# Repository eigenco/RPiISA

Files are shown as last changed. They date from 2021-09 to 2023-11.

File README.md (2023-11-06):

# RPiISA
Raspberry Pi to ISA bus, including Adlib emulation and PCB

Emulator to ISA (e.g. VGA-adapter), i.e. files in the directories beginning 20231105, correspond to this video: 

https://www.youtube.com/watch?v=V3mTAtPauRs

Portions of the emulator code are from this project: https://github.com/adriancable/8086tiny

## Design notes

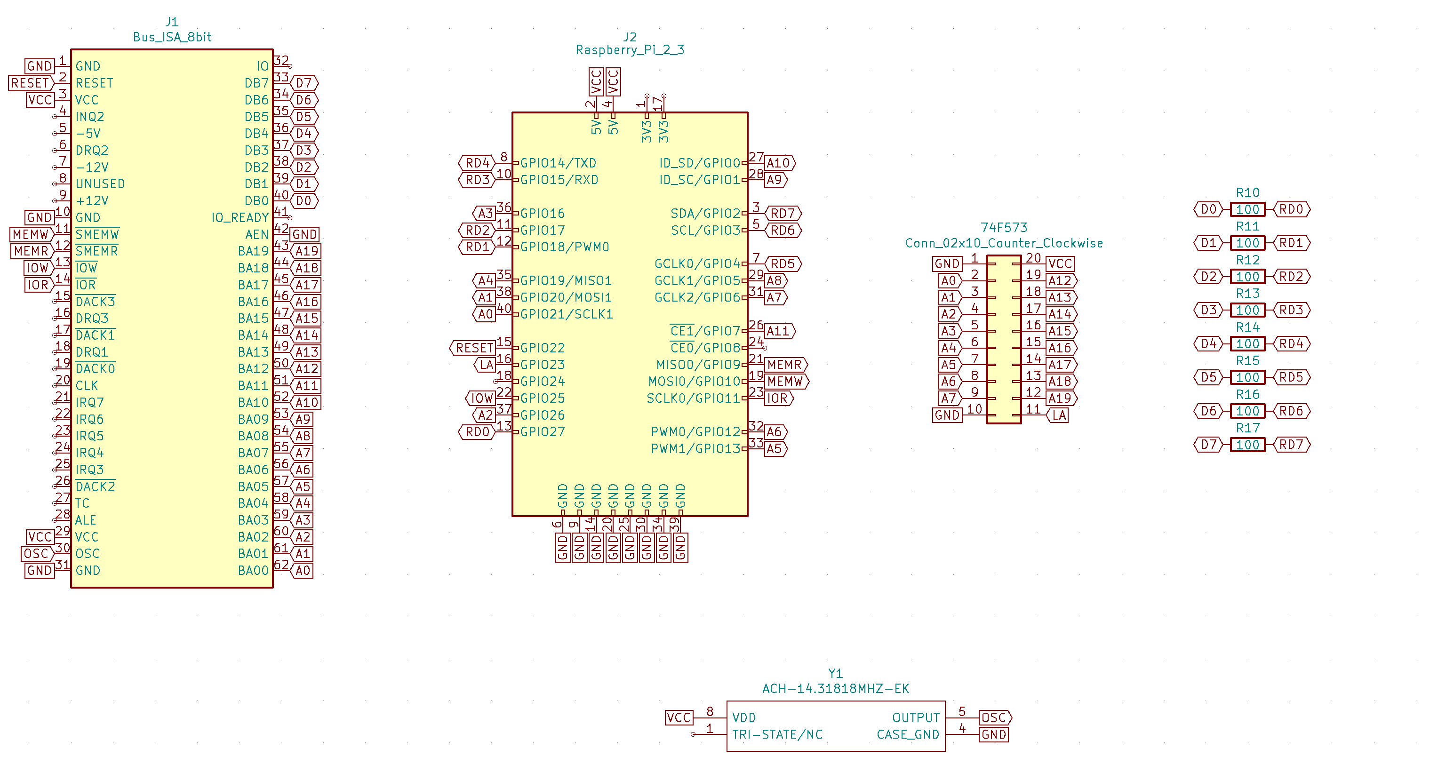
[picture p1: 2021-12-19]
schematic.png

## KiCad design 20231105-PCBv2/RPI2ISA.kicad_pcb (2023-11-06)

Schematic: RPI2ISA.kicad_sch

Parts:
J1: Bus_ISA_8bit; BUS_PC
J2: Raspberry_Pi_2_3; PinHeader_2x20_P2.54mm_Vertical
J3: Conn_02x10_Counter_Clockwise; DIP-20_W7.62mm_Socket
Y1: ACH-14.31818MHZ-EK; ACH16000MHZEK; Mouser Part Number 815-ACH-14.31818EK

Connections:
A0: J1.62 (BA00), J2.40 (GPIO21/SCLK1), J3.2
A1: J1.61 (BA01), J2.38 (GPIO20/MOSI1), J3.3
A2: J1.60 (BA02), J2.37 (GPIO26), J3.4
A3: J1.59 (BA03), J2.36 (GPIO16), J3.5
A4: J1.58 (BA04), J2.35 (GPIO19/MISO1), J3.6
A5: J1.57 (BA05), J2.33 (PWM1/GPIO13), J3.7
A6: J1.56 (BA06), J2.32 (PWM0/GPIO12), J3.8
A7: J1.55 (BA07), J2.31 (GCLK2/GPIO6), J3.9
A8: J1.54 (BA08), J2.29 (GCLK1/GPIO5)
A9: J1.53 (BA09), J2.28 (ID_SC/GPIO1)
A10: J1.52 (BA10), J2.27 (ID_SD/GPIO0)
A11: J1.51 (BA11), J2.26 (~CE1/GPIO7)
A12: J1.50 (BA12), J3.19
A13: J1.49 (BA13), J3.18
A14: J1.48 (BA14), J3.17
A15: J1.47 (BA15), J3.16
A16: J1.46 (BA16), J3.15
A17: J1.45 (BA17), J3.14
A18: J1.44 (BA18), J3.13
A19: J1.43 (BA19), J3.12
D0: J1.40 (DB0), J2.13 (GPIO27)
D1: J1.39 (DB1), J2.12 (GPIO18/PWM0)
D2: J1.38 (DB2), J2.11 (GPIO17)
D3: J1.37 (DB3), J2.10 (GPIO15/RXD)
D4: J1.36 (DB4), J2.8 (GPIO14/TXD)
D5: J1.35 (DB5), J2.7 (GCLK0/GPIO4)
D6: J1.34 (DB6), J2.5 (SCL/GPIO3)
D7: J1.33 (DB7), J2.3 (SDA/GPIO2)
GND: J1.1 (GND), J1.10 (GND), J1.31 (GND), J1.42 (AEN), J2.6 (GND), J2.9 (GND), J2.14 (GND), J2.20 (GND), J2.25 (GND), J2.30 (GND), J2.34 (GND), J2.39 (GND), J3.1, J3.10, Y1.4
IOR: J1.14 (~IOR), J2.23 (SCLK0/GPIO11)
IOW: J1.13 (~IOW), J2.22 (GPIO25)
LA: J2.16 (GPIO23), J3.11
MEMR: J1.12 (~SMEMR), J2.21 (MISO0/GPIO9)
MEMW: J1.11 (~SMEMW), J2.19 (MOSI0/GPIO10)
OSC: J1.30 (OSC), Y1.5
READY: J1.41 (IO_READY), J2.18 (GPIO24)
RESET: J1.2 (RESET), J2.15 (GPIO22)
VCC: J1.3 (VCC), J1.29 (VCC), J2.2 (5V), J2.4 (5V), J3.20, Y1.8

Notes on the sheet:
TODO -Add missing pullup (10k) for READY

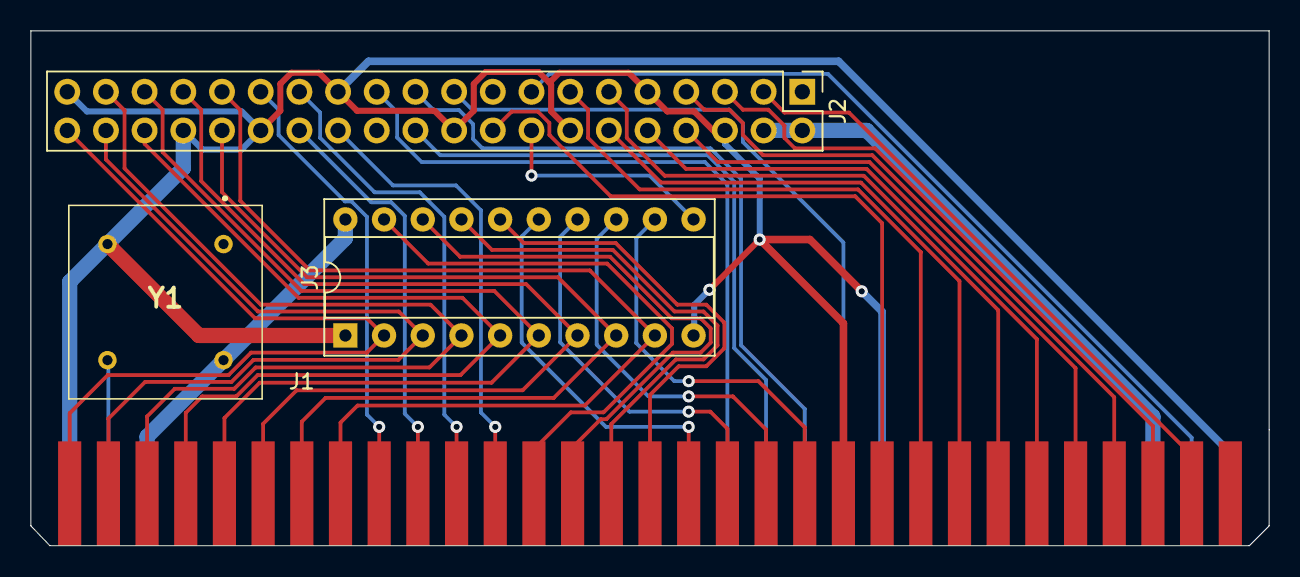
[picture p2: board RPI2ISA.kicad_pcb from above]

Board: 2 copper layers, 81.3 x 33.8 mm, 4 parts (0 on the bottom side), 38 nets.

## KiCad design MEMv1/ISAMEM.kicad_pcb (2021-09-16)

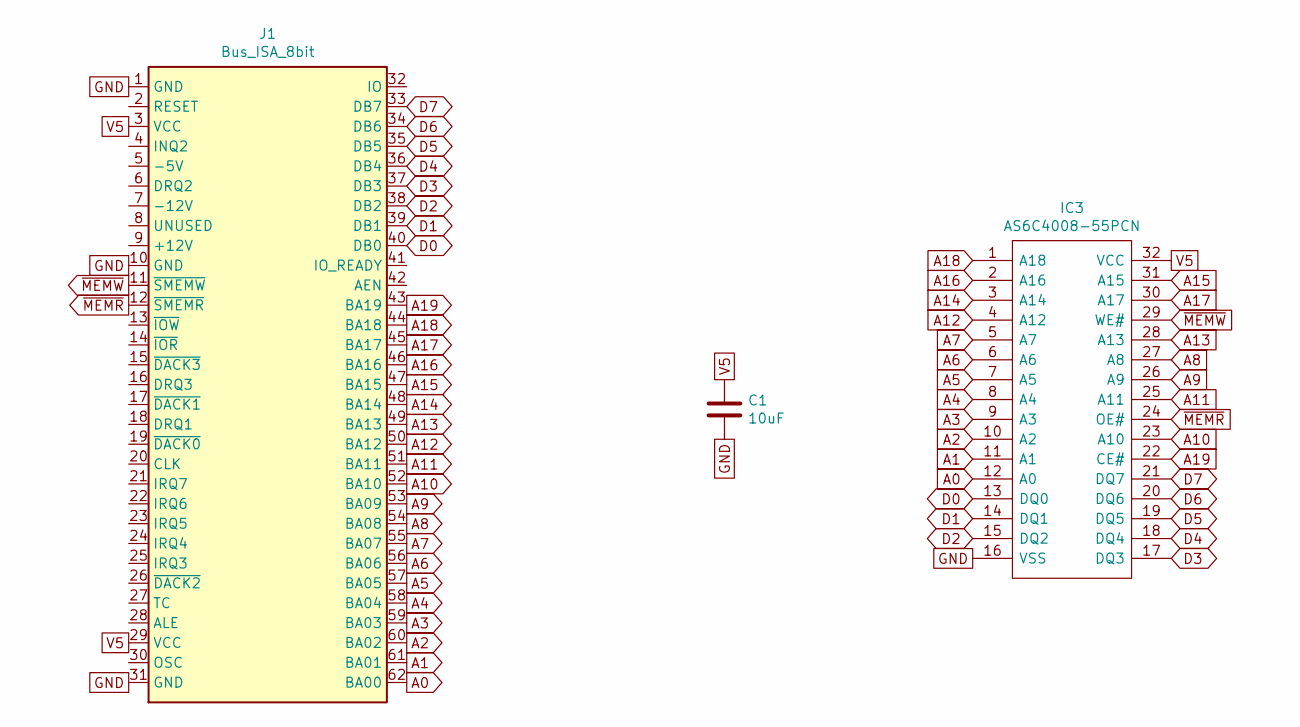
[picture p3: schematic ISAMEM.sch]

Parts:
C1: 10uF; C_0603_1608Metric
IC3: AS6C4008-55PCN; DIP1524W58P254L4191H406Q32N; Mouser Part Number 913-AS6C4008-55PCN
J1: Bus_ISA_8bit; BUS_PC

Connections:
A0: IC3.12 (A0), J1.62 (BA00)
A1: IC3.11 (A1), J1.61 (BA01)
A2: IC3.10 (A2), J1.60 (BA02)
A3: IC3.9 (A3), J1.59 (BA03)
A4: IC3.8 (A4), J1.58 (BA04)
A5: IC3.7 (A5), J1.57 (BA05)
A6: IC3.6 (A6), J1.56 (BA06)
A7: IC3.5 (A7), J1.55 (BA07)
A8: IC3.27 (A8), J1.54 (BA08)
A9: IC3.26 (A9), J1.53 (BA09)
A10: IC3.23 (A10), J1.52 (BA10)
A11: IC3.25 (A11), J1.51 (BA11)
A12: IC3.4 (A12), J1.50 (BA12)
A13: IC3.28 (A13), J1.49 (BA13)
A14: IC3.3 (A14), J1.48 (BA14)
A15: IC3.31 (A15), J1.47 (BA15)
A16: IC3.2 (A16), J1.46 (BA16)
A17: IC3.30 (A17), J1.45 (BA17)
A18: IC3.1 (A18), J1.44 (BA18)
A19: IC3.22 (CE#), J1.43 (BA19)
D0: IC3.13 (DQ0), J1.40 (DB0)
D1: IC3.14 (DQ1), J1.39 (DB1)
D2: IC3.15 (DQ2), J1.38 (DB2)
D3: IC3.17 (DQ3), J1.37 (DB3)
D4: IC3.18 (DQ4), J1.36 (DB4)
D5: IC3.19 (DQ5), J1.35 (DB5)
D6: IC3.20 (DQ6), J1.34 (DB6)
D7: IC3.21 (DQ7), J1.33 (DB7)
GND: C1.2, IC3.16 (VSS), J1.1 (GND), J1.10 (GND), J1.31 (GND)
V5: C1.1, IC3.32 (VCC), J1.3 (VCC), J1.29 (VCC)
~MEMR: IC3.24 (OE#), J1.12 (~SMEMR)
~MEMW: IC3.29 (WE#), J1.11 (~SMEMW)

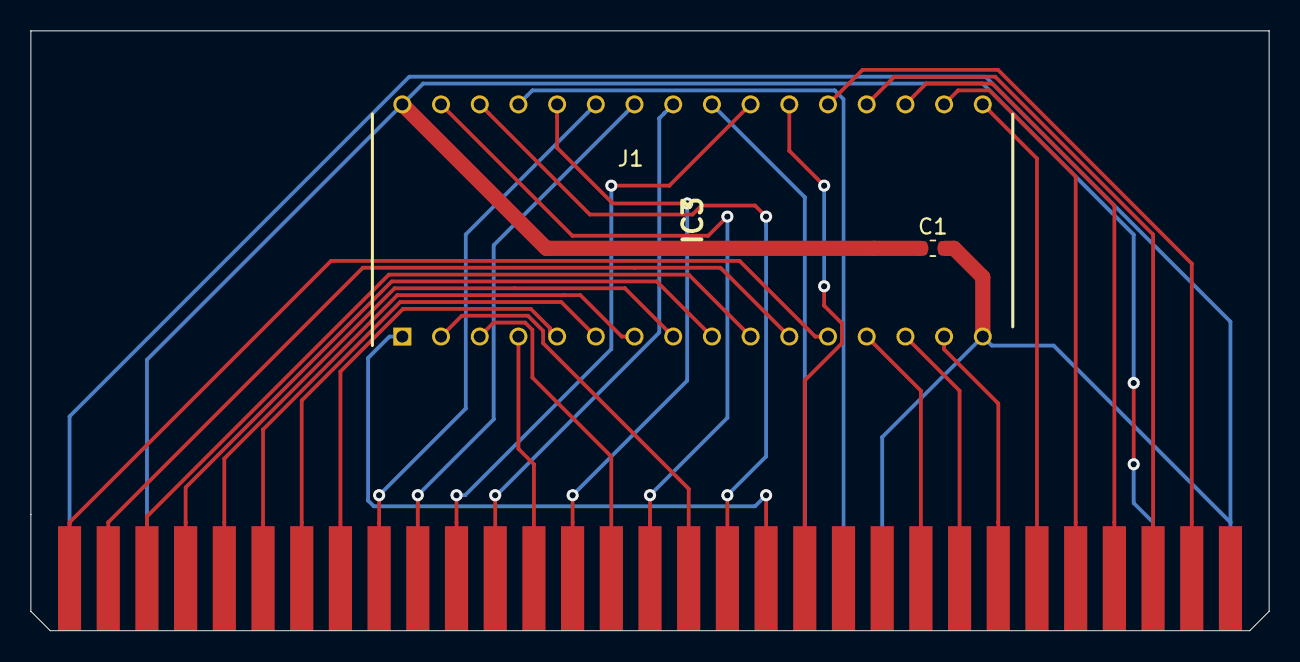
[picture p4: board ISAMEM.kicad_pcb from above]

Board: 2 copper layers, 81.3 x 39.4 mm, 3 parts (0 on the bottom side), 32 nets.

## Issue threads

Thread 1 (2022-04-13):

Great Idea!

zhblue, 2022-04-13:
can this project develop a special version of dosbox-x which can use real isa hardware with dosbox in the pi ?

eigenco, 2022-04-13:
Possibly, at least to some degree. I have controlled Adlib, VGA and XT-CF with the RPi in ISA bus successfully, but all these devices allowed one to operate slower than ISA standard (or to be exact, linux has highly nondeterministic timing respect to ISA timescales which can be a problem even if speed itself wasn't). This sort of timing doesn't matter for some devices, but some other devices need tight timings which likely need bare metal and even then it might be difficult.

Another issue is that RPi doesn't have enough pins for general ISA support, only a subset of ISA, so for example this board can't do IRQ and DMA for the moment. One could try multiplexing pins, but if there are timing issues, then this just makes them worse. All in all, I suppose what you're asking could in principle be done for a bunch of devices, but maybe not all. The easiest are asynchronous devices which can be addressed using only io ports, such as adlib and xt-cf.

Recently my interest has been the other more difficult direction where RPi acts as a device in the bus instead of controlling devices in the bus, but a general project where RPi can be configured whichever way could be interesting.

zhblue, 2022-04-15:
even more interesting, i mean the idea of plug rpi into isa bus as a device.
what name is the project ? will it works on pci or pci-e ?

kaithar, 2022-10-19:
I'm trying to work out exactly what backplane this is intended to plug into... is it meant for an ISA slot on a on a motherboard (sharing the bus effectively) or for a backplane more like the old kit computers (when everything was on a card, though I don't think those were ISA)?

eigenco, 2022-10-20:
Generally speaking just a regular ISA slot on a regular motherboard. Doesn't matter if it's and old backplane for 8088 or a more modern motherboard for Pentium II machine with 16-bit ISA slots (8-bit card still work normally). I have operated this board in two different configurations. One where the board is "slave" (motherboard has CPU) and one where the board is "master" (RPi acts like CPU). When the board is CPU, then a passive backplane is needed.

Here's a video of the "slave" way: https://www.youtube.com/watch?v=M7Lov_MH6n8 (this is a more proto-stage board)
Here's a video of the "master" way: https://www.youtube.com/watch?v=z1f5ZD5BoNA

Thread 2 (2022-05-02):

License?

polpo, 2022-05-02:
Hi,

I am in the process of experimenting with creating a Gravis Ultrasound emulator, using your project as a basis. There are just enough GPIO pins to do IRQ and DMA for GUS (possibly, depending on how loose things can be with timing – hence the experimentation phase).

What is the license for the code and hardware design? Is the code GPL 2.0, because it uses some DOSBox code?

eigenco, 2022-05-03:
I suppose GPL 2.0 is fine. I haven't thought about it really and just put it out there being ok people using both code and hardware freely.

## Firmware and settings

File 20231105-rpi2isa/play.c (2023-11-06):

#include <stdio.h>
#include <stdlib.h>
#include <wiringPi.h>
#include <unistd.h>

#define LA 23
#define IOW 25
#define IOR 11
#define MEMR 9
#define MEMW 10
#define RESET 22

#define D0 27
#define D1 18
#define D2 17
#define D3 15
#define D4 14
#define D5 4
#define D6 3
#define D7 2

#define A0 21
#define A1 20
#define A2 26
#define A3 16
#define A4 19
#define A5 13
#define A6 12
#define A7 6
#define A8 5
#define A9 1
#define A10 0
#define A11 7

void setaddr(unsigned short addr) {
  digitalWrite(A0, addr & 1); addr >>= 1;
  digitalWrite(A1, addr & 1); addr >>= 1;
  digitalWrite(A2, addr & 1); addr >>= 1;
  digitalWrite(A3, addr & 1); addr >>= 1;
  digitalWrite(A4, addr & 1); addr >>= 1;
  digitalWrite(A5, addr & 1); addr >>= 1;
  digitalWrite(A6, addr & 1); addr >>= 1;
  digitalWrite(A7, addr & 1); addr >>= 1;
  digitalWrite(A8, addr & 1); addr >>= 1;
  digitalWrite(A9, addr & 1); addr >>= 1;
  digitalWrite(A10, addr & 1); addr >>= 1;
  digitalWrite(A11, addr & 1);
}

void setdata(unsigned char data) {
  digitalWrite(D0, data & 1); data >>= 1;
  digitalWrite(D1, data & 1); data >>= 1;
  digitalWrite(D2, data & 1); data >>= 1;
  digitalWrite(D3, data & 1); data >>= 1;
  digitalWrite(D4, data & 1); data >>= 1;
  digitalWrite(D5, data & 1); data >>= 1;
  digitalWrite(D6, data & 1); data >>= 1;
  digitalWrite(D7, data & 1);
}

unsigned char getdata() {
  unsigned char data;

  data  = digitalRead(D7); data <<= 1;
  data |= digitalRead(D6); data <<= 1;
  data |= digitalRead(D5); data <<= 1;
  data |= digitalRead(D4); data <<= 1;
  data |= digitalRead(D3); data <<= 1;
  data |= digitalRead(D2); data <<= 1;
  data |= digitalRead(D1); data <<= 1;
  data |= digitalRead(D0);

  return data;
}

/*
void setinput() {
  pinMode(D0, INPUT);
  pinMode(D1, INPUT);
  pinMode(D2, INPUT);
  pinMode(D3, INPUT);
  pinMode(D4, INPUT);
  pinMode(D5, INPUT);
  pinMode(D6, INPUT);
  pinMode(D7, INPUT);
}

void setoutput() {
  pinMode(D0, OUTPUT);
  pinMode(D1, OUTPUT);
  pinMode(D2, OUTPUT);
  pinMode(D3, OUTPUT);
  pinMode(D4, OUTPUT);
  pinMode(D5, OUTPUT);
  pinMode(D6, OUTPUT);
  pinMode(D7, OUTPUT);
}
*/

void outb(unsigned short addr, unsigned char data) {
  //setoutput();
  setaddr(addr);
  setdata(data);
  digitalWrite(IOW, 0);
  usleep(1);
  digitalWrite(IOW, 1);
}

void wr_adlib(unsigned char reg, unsigned char value) {
  outb(0x388, reg); usleep(3);
  outb(0x389, value), usleep(22);
}

int main() {
  int i, j, k, x, y, z, song_register, song_data, song_wait, song_offset = 0;
  unsigned char buffer[57306];
  FILE *f;

  f = fopen("lemmings.dat", "rb");
  fread(buffer, 1, 57306, f);
  fclose(f);

  wiringPiSetupGpio();

  pinMode(LA, OUTPUT);
  pinMode(IOW, OUTPUT);
  pinMode(IOR, OUTPUT);
  pinMode(MEMW, OUTPUT);
  pinMode(MEMR, OUTPUT);
  pinMode(RESET, OUTPUT);
  digitalWrite(IOW, 1);
  digitalWrite(IOR, 1);
  digitalWrite(MEMW, 1);
  digitalWrite(MEMR, 1);

  // CONFIGURE ADDRESS PINS
  pinMode(A0, OUTPUT);
  pinMode(A1, OUTPUT);
  pinMode(A2, OUTPUT);
  pinMode(A3, OUTPUT);
  pinMode(A4, OUTPUT);
  pinMode(A5, OUTPUT);
  pinMode(A6, OUTPUT);
  pinMode(A7, OUTPUT);
  pinMode(A8, OUTPUT);
  pinMode(A9, OUTPUT);
  pinMode(A10, OUTPUT);
  pinMode(A11, OUTPUT);

  // CONFIGURE DATA PINS
  pinMode(D0, OUTPUT);
  pinMode(D1, OUTPUT);
  pinMode(D2, OUTPUT);
  pinMode(D3, OUTPUT);
  pinMode(D4, OUTPUT);
  pinMode(D5, OUTPUT);
  pinMode(D6, OUTPUT);
  pinMode(D7, OUTPUT);

  // RESET BUS
  digitalWrite(RESET, 1); usleep(100000);
  digitalWrite(RESET, 0); usleep(100000);

  // PLAY THE LEMMINGS SONG USING ADLIB
  for(;;) {
    song_register = buffer[song_offset];
    song_offset++;
    if(song_register==0) {
      song_wait  = (buffer[song_offset+1] << 8) | buffer[song_offset+0];
      song_offset += 2;
      usleep(1786*song_wait);
    } else {
      song_data = buffer[song_offset]; song_offset++;
      song_wait = buffer[song_offset]; song_offset++;
      wr_adlib(song_register, song_data);
      usleep(1786*song_wait);
    }
    if(song_offset>57300) {
      for(i=0; i<256; i++)
        wr_adlib(i, 0);
      exit(0);
    }
  }

  return 0;
}

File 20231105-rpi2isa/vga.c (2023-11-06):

// gcc -O2 vga.c -l wiringPi -o vga
#include <stdio.h>
#include <stdlib.h>
#include <wiringPi.h>
#include <unistd.h>

#define LA 23
#define IOW 25
#define IOR 11
#define MEMR 9
#define MEMW 10
#define RESET 22
#define READY 24

#define D0 27
#define D1 18
#define D2 17
#define D3 15
#define D4 14
#define D5 4
#define D6 3
#define D7 2

#define A00 21
#define A01 20
#define A02 26
#define A03 16
#define A04 19
#define A05 13
#define A06 12
#define A07 6
#define A08 5
#define A09 1
#define A10 0
#define A11 7

volatile int mode = 0;
volatile int oldaddr = 0;

void setaddr(int addr) {
  digitalWrite(A00, addr & 1); addr >>= 1;
  digitalWrite(A01, addr & 1); addr >>= 1;
  digitalWrite(A02, addr & 1); addr >>= 1;
  digitalWrite(A03, addr & 1); addr >>= 1;
  digitalWrite(A04, addr & 1); addr >>= 1;
  digitalWrite(A05, addr & 1); addr >>= 1;
  digitalWrite(A06, addr & 1); addr >>= 1;
  digitalWrite(A07, addr & 1); addr >>= 1;
  digitalWrite(A08, addr & 1); addr >>= 1;
  digitalWrite(A09, addr & 1); addr >>= 1;
  digitalWrite(A10, addr & 1); addr >>= 1;
  digitalWrite(A11, addr & 1);
}

void setdata(int data) {
  digitalWrite(D0, data & 1); data >>= 1;
  digitalWrite(D1, data & 1); data >>= 1;
  digitalWrite(D2, data & 1); data >>= 1;
  digitalWrite(D3, data & 1); data >>= 1;
  digitalWrite(D4, data & 1); data >>= 1;
  digitalWrite(D5, data & 1); data >>= 1;
  digitalWrite(D6, data & 1); data >>= 1;
  digitalWrite(D7, data & 1);
}

int getdata() {
  int data;

  data  = digitalRead(D7); data <<= 1;
  data |= digitalRead(D6); data <<= 1;
  data |= digitalRead(D5); data <<= 1;
  data |= digitalRead(D4); data <<= 1;
  data |= digitalRead(D3); data <<= 1;
  data |= digitalRead(D2); data <<= 1;
  data |= digitalRead(D1); data <<= 1;
  data |= digitalRead(D0);

  return data;
}

void setinput() {
  pinMode(D0, INPUT);
  pinMode(D1, INPUT);
  pinMode(D2, INPUT);
  pinMode(D3, INPUT);
  pinMode(D4, INPUT);
  pinMode(D5, INPUT);
  pinMode(D6, INPUT);
  pinMode(D7, INPUT);
  mode = 0;
}

void setoutput() {
  pinMode(D0, OUTPUT);
  pinMode(D1, OUTPUT);
  pinMode(D2, OUTPUT);
  pinMode(D3, OUTPUT);
  pinMode(D4, OUTPUT);
  pinMode(D5, OUTPUT);
  pinMode(D6, OUTPUT);
  pinMode(D7, OUTPUT);
  mode = 1;
}

int inb(int addr) {
  int data;

  if(mode==1) setinput();
  if( ((addr >> 12) & 0xFF) != ((oldaddr >> 12) & 0xFF) ) {
    setaddr((addr >> 12) & 0xFF);
    digitalWrite(LA, 1);
    digitalWrite(LA, 0);
    oldaddr = addr;
  }
  setaddr(addr & 0xFFF);
  digitalWrite(IOR, 0);
  usleep(1);
  data = getdata();
  digitalWrite(IOR, 1);

  return data;
}

void outb(int addr, int data) {
  if(mode==0) setoutput();
  if( ((addr >> 12) & 0xFF) != ((oldaddr >> 12) & 0xFF) ) {
    setaddr((addr >> 12) & 0xFF);
    digitalWrite(LA, 1);
    digitalWrite(LA, 0);
    oldaddr = addr;
  }
  setaddr(addr & 0xFFF);
  setdata(data);
  digitalWrite(IOW, 0);
  usleep(1);
  digitalWrite(IOW, 1);
}

void memw(int addr, int data) {
  if(mode==0) setoutput();
  if( ((addr >> 12) & 0xFF) != ((oldaddr >> 12) & 0xFF) ) {
    setaddr((addr >> 12) & 0xFF);
    digitalWrite(LA, 1);
    digitalWrite(LA, 0);
    oldaddr = addr;
  }
  setaddr(addr & 0xFFF);
  setdata(data);
  digitalWrite(MEMW, 0);
  while(!digitalRead(READY)) { printf("*"); fflush(stdout); }
  digitalWrite(MEMW, 1);
}

int memr(int addr) {
  int data;

  if(mode==1) setinput();
  if( ((addr >> 12) & 0xFF) != ((oldaddr >> 12) & 0xFF)) {
    setaddr((addr >> 12) & 0xFF);
    digitalWrite(LA, 1);
    digitalWrite(LA, 0);
    oldaddr = addr;
  }
  setaddr(addr & 0xFFF);
  digitalWrite(MEMR, 0);
  while(!digitalRead(READY)) { printf("*"); fflush(stdout); }
  data = getdata();
  digitalWrite(MEMR, 1);

  return data;
}

void init_vga(void) {
  for(int i=0; i<256; i++) memw(0xA0000+i, i);

  // RESET BUS
  digitalWrite(RESET, 1); usleep(100000);
  digitalWrite(RESET, 0); usleep(100000);

  // ET4000: set key
  outb(0x3bf, 3);
  outb(0x3d8, 0xa0);
  //usleep(100000);

  // ET4000: set clocks
  outb(0x3c4, 0x07);
  outb(0x3c5, 0xfc);

  // MISC register at port 3c2
  outb(0x3c2, 0x63);

  // ATC registers at port 3c0
  for(int i=0; i<0x10; i++) {
    inb(0x3da);
    outb(0x3c0, i);
    outb(0x3c0, i);
  }
  outb(0x3c0, 0x30); outb(0x3c0, 0x41);
  outb(0x3c0, 0x31); outb(0x3c0, 0x00);
  outb(0x3c0, 0x32); outb(0x3c0, 0x0f);
  outb(0x3c0, 0x33); outb(0x3c0, 0x00);
  outb(0x3c0, 0x34); outb(0x3c0, 0x00);

  // SEQ registers at port 3c4
  outb(0x3c4, 0x00); outb(0x3c5, 0x03);
  outb(0x3c4, 0x01); outb(0x3c5, 0x01);
  outb(0x3c4, 0x02); outb(0x3c5, 0x0f);
  outb(0x3c4, 0x03); outb(0x3c5, 0x00);
  outb(0x3c4, 0x04); outb(0x3c5, 0x0e);

  // GDC registers at port 3ce
  outb(0x3ce, 0x00); outb(0x3cf, 0x00);
  outb(0x3ce, 0x01); outb(0x3cf, 0x00);
  outb(0x3ce, 0x02); outb(0x3cf, 0x00);
  outb(0x3ce, 0x03); outb(0x3cf, 0x00);
  outb(0x3ce, 0x04); outb(0x3cf, 0x00);
  outb(0x3ce, 0x05); outb(0x3cf, 0x40);
  outb(0x3ce, 0x06); outb(0x3cf, 0x05);
  outb(0x3ce, 0x07); outb(0x3cf, 0x0f);
  outb(0x3ce, 0x08); outb(0x3cf, 0xff);

  // CRTC registers at port 3d4
  outb(0x3d4, 0x11); outb(0x3d5, 0x00);
  outb(0x3d4, 0x00); outb(0x3d5, 0x5f);
  outb(0x3d4, 0x01); outb(0x3d5, 0x4f);
  outb(0x3d4, 0x02); outb(0x3d5, 0x50);
  outb(0x3d4, 0x03); outb(0x3d5, 0x82);
  outb(0x3d4, 0x04); outb(0x3d5, 0x54);
  outb(0x3d4, 0x05); outb(0x3d5, 0x80);
  outb(0x3d4, 0x06); outb(0x3d5, 0xbf);
  outb(0x3d4, 0x07); outb(0x3d5, 0x1f);
  outb(0x3d4, 0x08); outb(0x3d5, 0x00);
  outb(0x3d4, 0x09); outb(0x3d5, 0x41);
  outb(0x3d4, 0x0a); outb(0x3d5, 0x00);
  outb(0x3d4, 0x0b); outb(0x3d5, 0x00);
  outb(0x3d4, 0x0c); outb(0x3d5, 0x00);
  outb(0x3d4, 0x0d); outb(0x3d5, 0x00);
  outb(0x3d4, 0x0e); outb(0x3d5, 0x00);
  outb(0x3d4, 0x0f); outb(0x3d5, 0x00);
  outb(0x3d4, 0x10); outb(0x3d5, 0x9c);
  outb(0x3d4, 0x11); outb(0x3d5, 0x8e);
  outb(0x3d4, 0x12); outb(0x3d5, 0x8f);
  outb(0x3d4, 0x13); outb(0x3d5, 0x28);
  outb(0x3d4, 0x14); outb(0x3d5, 0x40);
  outb(0x3d4, 0x15); outb(0x3d5, 0x96);
  outb(0x3d4, 0x16); outb(0x3d5, 0xb9);
  outb(0x3d4, 0x17); outb(0x3d5, 0xa3);
  outb(0x3d4, 0x18); outb(0x3d5, 0xff);

  /* Enable video */
  outb(0x3c0, 0x20);
  int j = inb(0x3da);

  for(int i=0; i<8000; i++) memw(0xA0000+i, i);

  /* Set palette */
  outb(0x3c6, 0xff); // PEL mask
  for(;;) {
    outb(0x3c8, 0);
    outb(0x3c9, rand() % 64);
    outb(0x3c9, rand() % 64);
    outb(0x3c9, rand() % 64);
    usleep(100000);
  }
/*
  outb(0x3c8, 0);    // Palette register
  for(int i=0; i<64; i++) {
    outb(0x3c9, i & 63);
    outb(0x3c9, 0);
    outb(0x3c9, 0);
  }
  for(int i=0; i<64; i++) {
    outb(0x3c9, 0);
    outb(0x3c9, i & 63);
    outb(0x3c9, 0);
  }
  for(int i=0; i<64; i++) {
    outb(0x3c9, 0);
    outb(0x3c9, 0);
    outb(0x3c9, i & 63);
  }
  for(int i=0; i<64; i++) {
    outb(0x3c9, i & 63);
    outb(0x3c9, i & 63);
    outb(0x3c9, i & 63);
  }
*/
}
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
